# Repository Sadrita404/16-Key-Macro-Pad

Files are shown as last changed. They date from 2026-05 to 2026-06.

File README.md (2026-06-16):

---

16 Keys Macro Pad

---

|Title | 16 Key Macro Pad|
|:-- |:--|
|Author | Sadrita Neogi|

---

## Overview
This is a macro pad that has 16 customizable switches. the keys are 4 x4 Layout . I will be mainly using it for controlling music. like play, pause, skip and replay and adding macro for opening any application

---

## Project Inspiration



### I want to make an Macro Pad  which is like this (I just draw it out of my imagination )

---
## PCB 

### For getting started I have choose Kicad for designing the PCB also the schematic 



---



---



---



---



---

## Case

### For the Case I have choose Fusion 360 for this project



---



---



---

## Top Plate 



---

### After Assembly



---



---



---

### Final Model



---



---



---

## Assembly Instructions :-

1) First we need to get the PCB and then startrd soldering the **SK6812 MINI LEDs** to all the pads of the PCB .

2) After that we need to add the **SeeedStudio XIAO** to the designated spot on the PCb .

3) Next we will solder the  **0.91 inch Blue OLED Display** to the PCB.

4) After that we will need to connect the SeeedStudio XIAO to the PC and upload the code given in the [FIRMWARE](https://github.com/Sadrita404/16-Key-Macro-Pad/blob/main/FIRMWARE/main.py) and use **Arduino IDE** to upload the code .

5) After that we will take our 3d Printed PCB Case and and screw the pcb to the case .

6) Then we will add the 3d Printed top Plate to the Case and fix it.

7) After that we will put the  Switches in the PCB gently , to all the Places.

8) And then we will add the Key Caps to the Switches.

9) The last step connect the Keyboard to the PC and start using it...

---

Macro Pad Poster

---

## Bill Of Material (BOM)
| Name | Purpose | Qty | Total Price (USD) | Component Link | Distributor |
|---|---|---|---|---|---|
| PCB | For adding all the component | 5 | $10.00 | [Link](https://jlcpcb.com/) | JLCPCB |
| 0.91 inch Blue OLED Display | For the Display to add in the PCB | 1 | $1.61 | [Link](https://robocraze.com/products/0-91-inch-blue-oled-display-module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) | Robocraze |
| M3 Heatset | For securing the PCB with the case | 4 | $0.10 | [Link](https://onlyscrews.in/products/m4-x-4mm-brass-threaded-inserts?variant=49091565650233) | Onlyscrews |
| M3x16 Bolts | For securing the PCB with the case | 16 | $0.08 | [Link](https://onlyscrews.in/products/phillips-csk-m3-x-16mm-pack-of-20?variant=48463065383225) | Onlyscrews |
| XIAO RP2040 | For Controlling the PCB | 1 | $6.35 | [Link](https://robocraze.com/products/seeed-studio-xiao-rp2040-development-board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) | Robocraze |
| SK6812 MINI LEDs | For adding to the PCB (RGB) | 16 | - | [Link](https://www.desertcart.in/products/729031642-50pcs-sk6812-mini-e-rgb-similar-with-ws2812b-sk6812-3228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) | Self - Source |
| Blank DSA Keycaps | For adding to the switches | 16 | $2.24 | [Link](https://meckeys.com/shop/accessories/keyboard-accessories/keycaps/blank-dsa-keycaps-1u/) | Meckeys |
| Cherry MX Switches | For the PCB where I need to place the Switch | 16 | $3.39 | [Link](https://neomacro.in/products/outemu-lemon-v3-silent?variant=50885007147286) | Neomacro |
| 1n4148 diodes | For PCB | 16 | $0.21 | [Link](https://robu.in/product/1n4148-1w-zener-diode-pack-of-50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) | Robu |
|  Total | | | | | $25.98  |
## For 3d Printing I have use Legion where the cost is included in the Shipping
|Tax (USD)| Shipping (USD)|
|:-- | :--|
|$14.52 | $9|
| Total (USD)(Including BOM) |  $49.50  |
| Round Off Total (USD) |  $50  |

---

#### Project Under [Hack Club](https://hackclub.com/)

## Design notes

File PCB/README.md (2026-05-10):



---



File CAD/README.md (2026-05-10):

I have given the f3d , f3z , step & stl file of the model



---



---



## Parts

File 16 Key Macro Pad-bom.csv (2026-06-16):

Name | Purpose | Quantity | Total Cost (USD) | Link | Distributor
1n4148 diodes | For PCB | 16 | 0.21 | https://robu.in/product/1n4148-1w-zener-diode-pack-of-50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 | Robu
PCB | For adding all the component | 5 | 12.00 | https://jlcpcb.com/ | jlcpcb
0.91 inch Blue OLED Display | For the Display to add in the PCB | 1 | 1.61 | https://robocraze.com/products/0-91-inch-blue-oled-display-module?variant=40194383413401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 | Robocraze
M3 Heatset | For securing the PCB with the case | 4 | 0.10 | https://onlyscrews.in/products/m4-x-4mm-brass-threaded-inserts?variant=49091565650233 | Onlyscrews
M3x16 Bolts | For securing the PCB with the case | 16 | 0.08 | https://onlyscrews.in/products/phillips-csk-m3-x-16mm-pack-of-20?variant=48463065383225 | Onlyscrews
XIAO RP2040 | For Controlling the PCB | 1 | 6.35 | https://robocraze.com/products/seeed-studio-xiao-rp2040-development-board?variant=47742255562976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 | Robocraze
SK6812 MINI LEDs | For adding to the PCB (RGB) | 16 | 0.00 |  | Self Sorced
Blank DSA Keycaps | For adding to the switches | 16 | 2.24 | https://meckeys.com/shop/accessories/keyboard-accessories/keycaps/blank-dsa-keycaps-1u/ | Meckeys
Cherry MX Switches | For the PCB where I need to place the Switch | 16 | 3.39 | https://neomacro.in/products/outemu-lemon-v3-silent?variant=50885007147286 | Neomacro

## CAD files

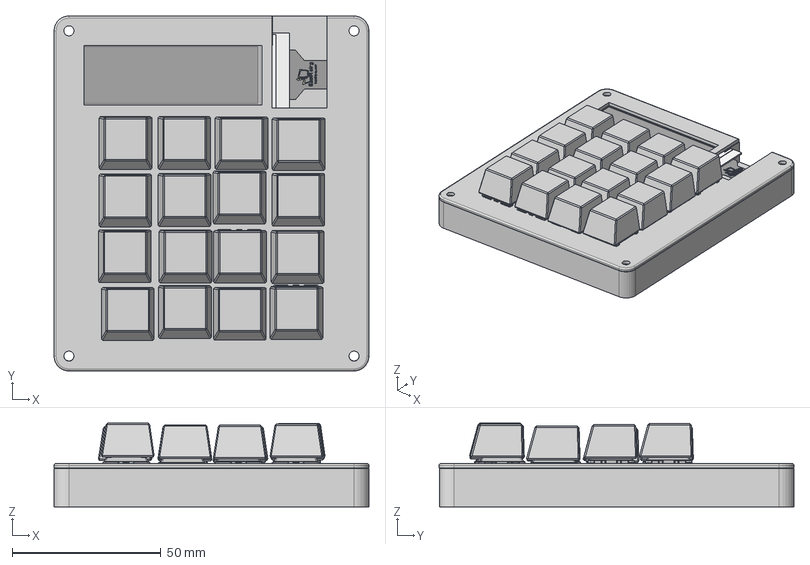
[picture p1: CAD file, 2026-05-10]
CAD/ASSEMBLY/Sadrita 16 pad Assembly step file.step
106.0 x 119.5 x 28.2 mm
Bens macro pad lid
ER-OLED2.45-1
MX Öá °´¼ü¡ä_¨¹ ___¡§1 x 16
MX Öá ÖáÌå¨¢¨¬ _¡§¡é¡§__ x 16
MXÖá ÎÞÃ±LEDLEDLED x 16
MXÖá ÖáÌå µ×²¿ ¦Ì¡ Á2__Ä¬ÈÏ_¨¢2____¨¨_ x 16
Õë½Å___Ä¬ÈÏ__¨¨ _ x 16

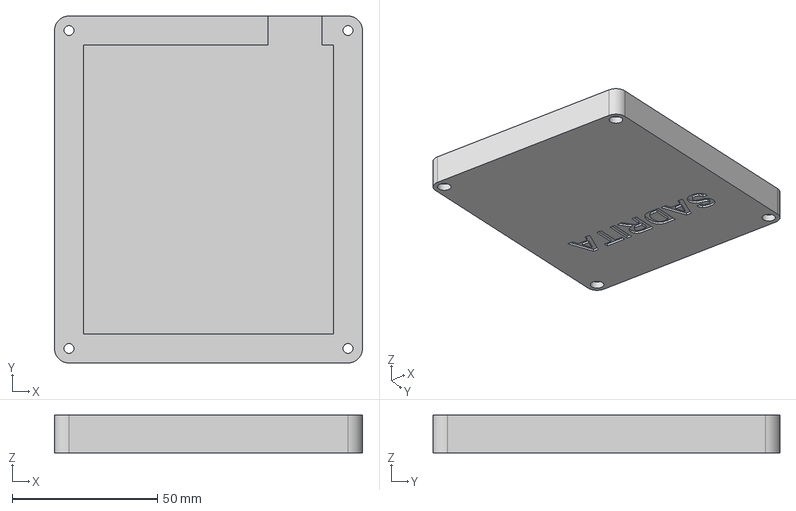
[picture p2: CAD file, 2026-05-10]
CAD/Case/Sadrita 16 pad Case.step
106.0 x 119.4 x 13.0 mm

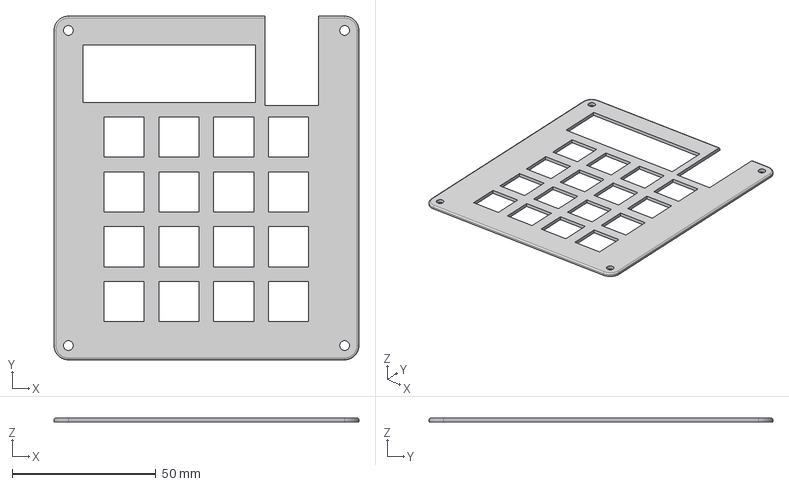
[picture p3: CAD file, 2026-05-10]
CAD/Top Plate/Sadrita 16 pad Top Plate.step
106.0 x 119.5 x 1.50 mm

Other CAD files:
CAD/ASSEMBLY/Sadrita 16 pad Assembly f3z.f3z
CAD/Case/Sadrita 16 pad Case.f3d
CAD/Case/Sadrita 16 pad Case.stl
CAD/Top Plate/Sadrita 16 pad Top Plate.f3d
CAD/Top Plate/Sadrita 16 pad Top Plate.stl

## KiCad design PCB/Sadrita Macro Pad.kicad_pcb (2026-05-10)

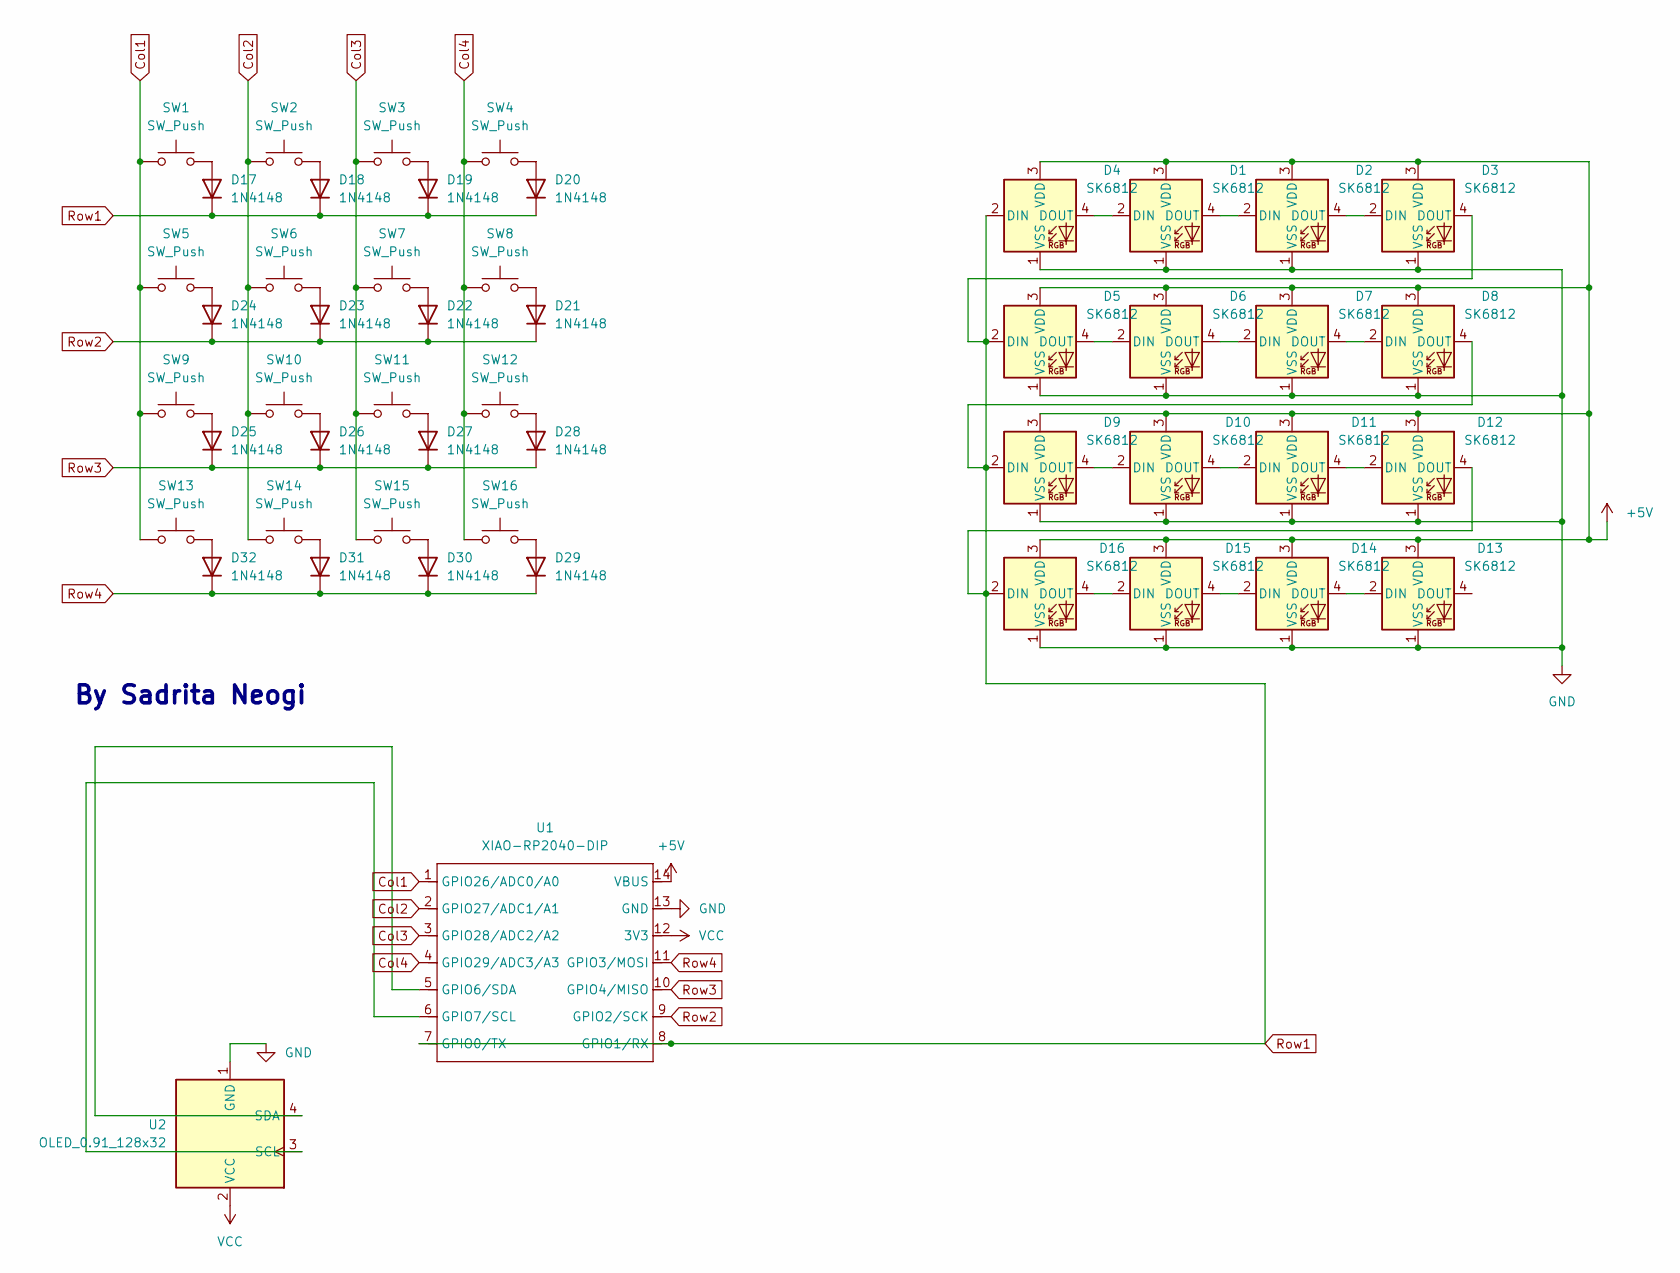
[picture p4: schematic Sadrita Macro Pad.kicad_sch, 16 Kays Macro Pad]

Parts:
D1, D2, D3, D4, D5, D6, D7, D8, D9, D10, D11, D12, D13, D14, D15, D16: SK6812; MX_SK6812MINI-E_REV
D17, D18, D19, D20, D21, D22, D23, D24, D25, D26, D27, D28, D29, D30, D31, D32: 1N4148; D_DO-35_SOD27_P7.62mm_Horizontal
SW1, SW2, SW3, SW4, SW5, SW6, SW7, SW8, SW9, SW10, SW11, SW12, SW13, SW14, SW15, SW16: SW_Push; SW_Cherry_MX_1.00u_PCB
U1: XIAO-RP2040-DIP
U2: OLED_0.91_128x32

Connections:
+5V: D1.3 (VDD), D2.3 (VDD), D3.3 (VDD), D4.3 (VDD), D5.3 (VDD), D6.3 (VDD), D7.3 (VDD), D8.3 (VDD), D9.3 (VDD), D10.3 (VDD), D11.3 (VDD), D12.3 (VDD), D13.3 (VDD), D14.3 (VDD), D15.3 (VDD), D16.3 (VDD), U1.14 (VBUS)
Col1: SW1.1, SW5.1, SW9.1, SW13.1, U1.1 (GPIO26/ADC0/A0)
Col2: SW2.1, SW6.1, SW10.1, SW14.1, U1.2 (GPIO27/ADC1/A1)
Col3: SW3.1, SW7.1, SW11.1, SW15.1, U1.3 (GPIO28/ADC2/A2)
Col4: SW4.1, SW8.1, SW12.1, SW16.1, U1.4 (GPIO29/ADC3/A3)
GND: D1.1 (VSS), D2.1 (VSS), D3.1 (VSS), D4.1 (VSS), D5.1 (VSS), D6.1 (VSS), D7.1 (VSS), D8.1 (VSS), D9.1 (VSS), D10.1 (VSS), D11.1 (VSS), D12.1 (VSS), D13.1 (VSS), D14.1 (VSS), D15.1 (VSS), D16.1 (VSS), U1.13 (GND), U2.1 (GND)
unnamed: D1.2 (DIN), D4.4 (DOUT)
unnamed: D1.4 (DOUT), D2.2 (DIN)
unnamed: D2.4 (DOUT), D3.2 (DIN)
unnamed: D5.4 (DOUT), D6.2 (DIN)
unnamed: D6.4 (DOUT), D7.2 (DIN)
unnamed: D7.4 (DOUT), D8.2 (DIN)
unnamed: D9.4 (DOUT), D10.2 (DIN)
unnamed: D10.4 (DOUT), D11.2 (DIN)
unnamed: D11.4 (DOUT), D12.2 (DIN)
unnamed: D13.2 (DIN), D14.4 (DOUT)
unnamed: D14.2 (DIN), D15.4 (DOUT)
unnamed: D15.2 (DIN), D16.4 (DOUT)
unnamed: D17.2 (A), SW1.2
unnamed: D18.2 (A), SW2.2
unnamed: D19.2 (A), SW3.2
unnamed: D20.2 (A), SW4.2
unnamed: D21.2 (A), SW8.2
unnamed: D22.2 (A), SW7.2
unnamed: D23.2 (A), SW6.2
unnamed: D24.2 (A), SW5.2
unnamed: D25.2 (A), SW9.2
unnamed: D26.2 (A), SW10.2
unnamed: D27.2 (A), SW11.2
unnamed: D28.2 (A), SW12.2
unnamed: D29.2 (A), SW16.2
unnamed: D30.2 (A), SW15.2
unnamed: D31.2 (A), SW14.2
unnamed: D32.2 (A), SW13.2
unnamed: U1.5 (GPIO6/SDA), U2.4 (SDA)
unnamed: U1.6 (GPIO7/SCL), U2.3 (SCL)
Row2: D21.1 (K), D22.1 (K), D23.1 (K), D24.1 (K), U1.9 (GPIO2/SCK)
Row3: D25.1 (K), D26.1 (K), D27.1 (K), D28.1 (K), U1.10 (GPIO4/MISO)
Row4: D29.1 (K), D30.1 (K), D31.1 (K), D32.1 (K), U1.11 (GPIO3/MOSI)
VCC: U1.12 (3V3), U2.2 (VCC)

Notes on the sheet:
By Sadrita Neogi

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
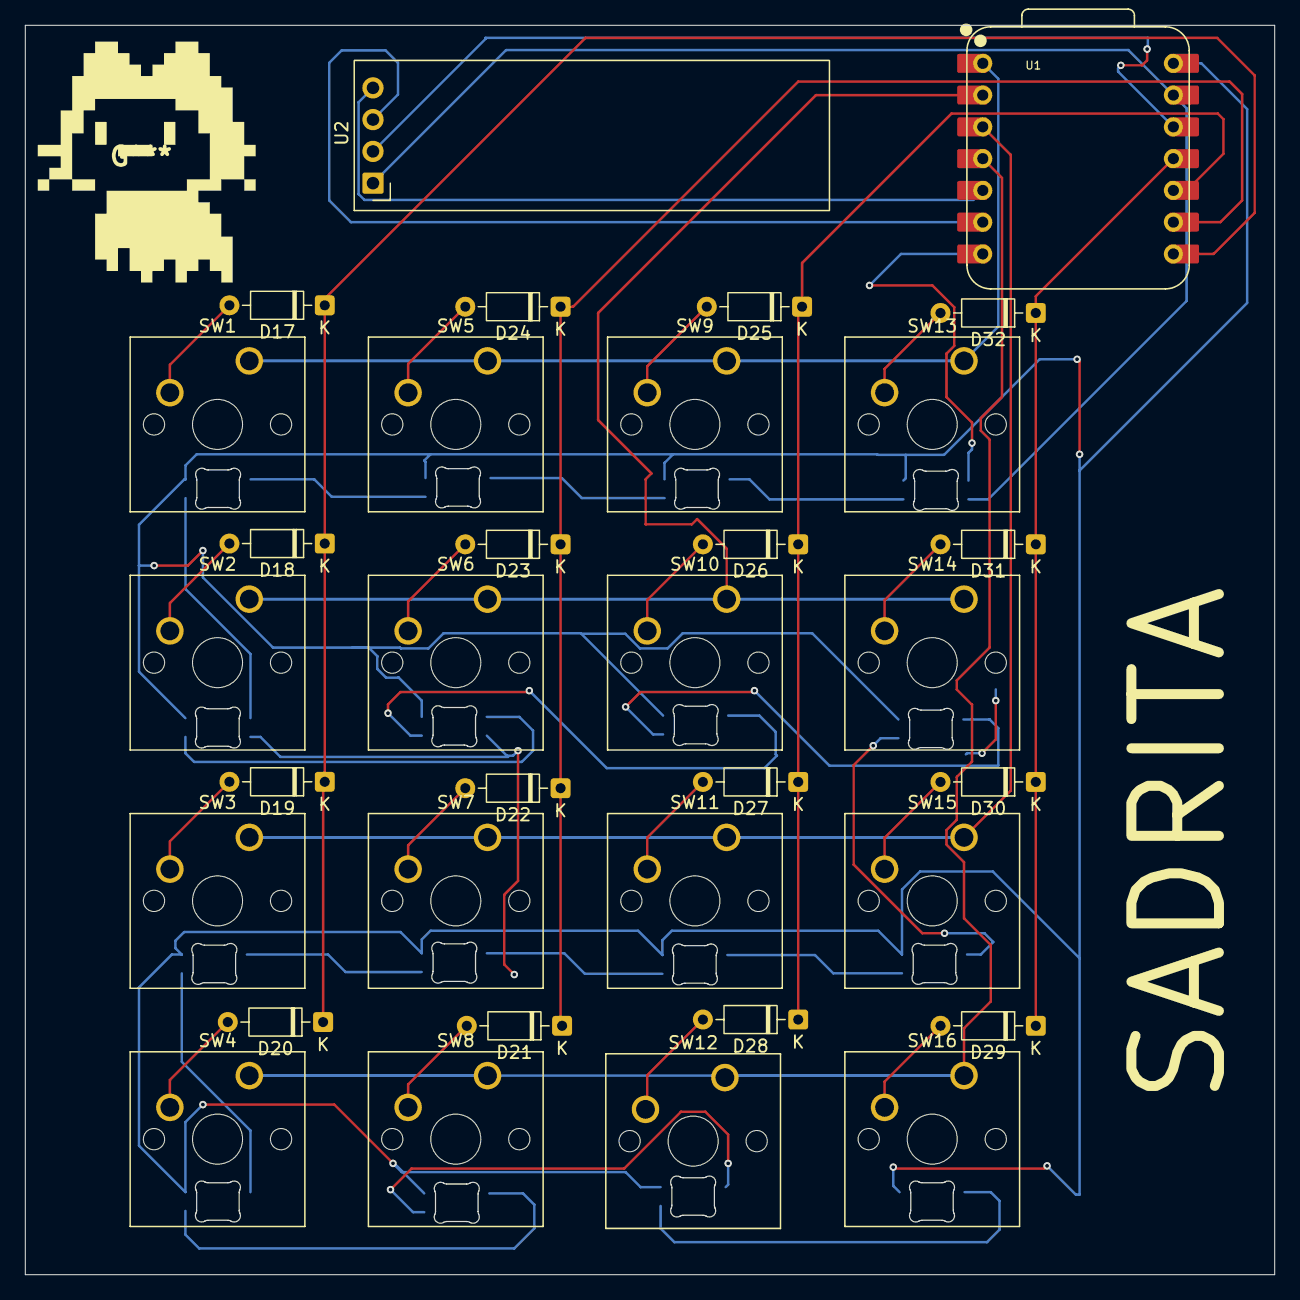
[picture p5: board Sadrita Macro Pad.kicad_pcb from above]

Board: 2 copper layers, 99.9 x 99.9 mm, 50 parts (0 on the bottom side), 45 nets.

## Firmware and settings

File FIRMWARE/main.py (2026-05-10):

# You import all the IOs of your board
import board

# These are imports from the kmk library
from kmk.kmk_keyboard import KMKKeyboard
from kmk.scanners.keypad import KeysScanner
from kmk.keys import KC
from kmk.modules.macros import Press, Release, Tap, Macros

# This is the main instance of your keyboard
keyboard = KMKKeyboard()

# Add the macro extension
macros = Macros()
keyboard.modules.append(macros)

# Define your pins here!
PINS = [board.D3, board.D4, board.D2, board.D1]

keyboard.col_pins = [board.GP26, board.GP27, board.GP28, board.GP29]
keyboard.row_pins = [board.GP1, board.GP2, board.GP3, board.GP4]

keyboard.keymap = [
    [KC.Macro(Press(KC.LALT), Tap(KC.F4), Release(KC.LALT)),],
    [KC.F13],
    [KC.F14],
    [KC.F15],
    [KC.F16],
    [KC.F17],
    [KC.F18],
    [KC.F19],
    [KC.F20],
    [KC.F21],
    [KC.F22],
    [KC.F23],
    [KC.F24],
    [KC.MACRO("BONK!")],
    [KC.MACRO(":pf:")],
    [KC.MACRO(":skulk:")]
]

# Start kmk!
if __name__ == '__main__':
    keyboard.go()
# By Sadrita Neogi

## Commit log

2026-05-10 BOM added
    [16 Key Macro Pad.csv]
2026-05-10 BOM added of the project ( csv )
    [16 Kay Macro Pad BOM .csv]
2026-06-16 Update 16 Kay Macro Pad BOM .csv
    [16 Kay Macro Pad BOM .csv]
